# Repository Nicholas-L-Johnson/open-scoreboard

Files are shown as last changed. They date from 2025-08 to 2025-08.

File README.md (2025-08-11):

## Open Scoreboard

This project is a pocket scoreboard with Android/iOS/WatchOS apps.

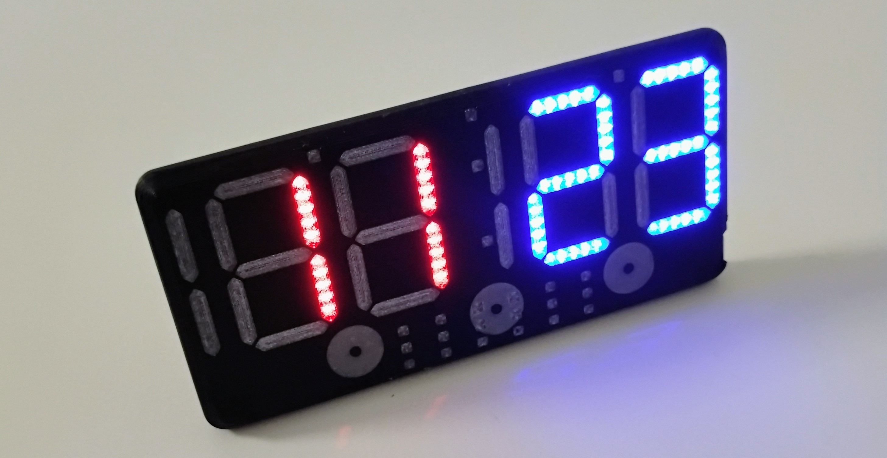
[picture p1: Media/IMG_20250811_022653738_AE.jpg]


The goal is a mass market product.  It beats out the existing devices on the market in features and price.



It really is small enough to fit in a pocket, and the battery lasts for up to 2 days of continuuous display on one charge.

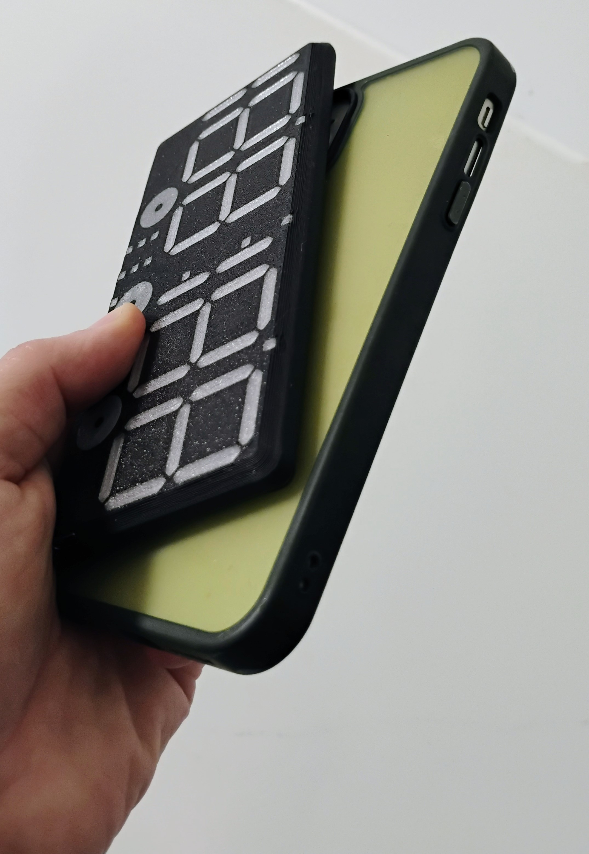
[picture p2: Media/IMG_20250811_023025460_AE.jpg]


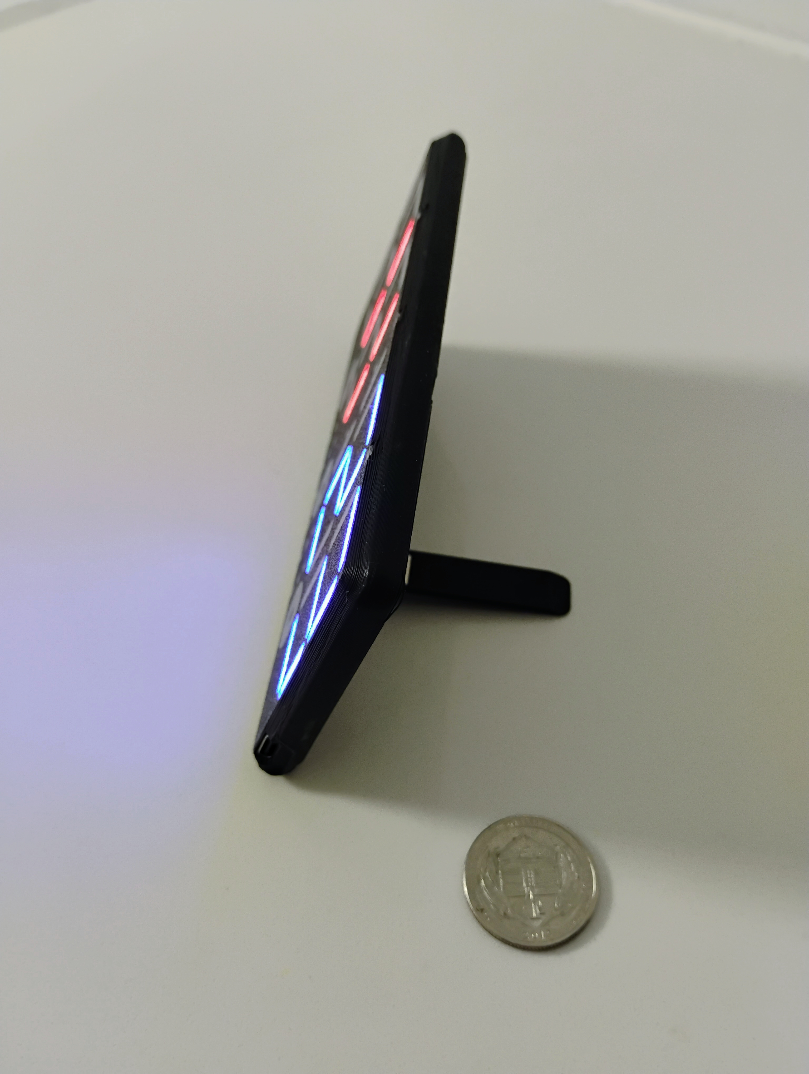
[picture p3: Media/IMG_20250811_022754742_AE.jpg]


It has some other modes too, a countdown timer and alarm clock


This project may be slightly doomed.  It will take about 35K to get the certifications, testing, and llc up to the level where these can be sold.  The real killer is the massive fee to use bluetooth.

I could seek a loan, but I am pretty against that at this point.  The app is not nearly ready, and it definitly needs to be migrated to a 4 layer board if I want to pass FCC testing.

Anyway, I'll keep working and maybe when it's ready there will be some cash I can spare on it.

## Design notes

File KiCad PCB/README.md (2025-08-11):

## PCB files

These are the hardware design files for the open scoreboard project.

The current design is based off of an nRF52833 with an RGB LED grid laid out as a scoreboard.

Version 0.1 controlled the LED's directly.  
This worked but required many pins and led to flickering and ghosting and lacked some creature comforts such as recharchable battery. 4 LEDs per segment also did not look great.

Version 0.2 attepted to switch to WLEDs.
This pulled far too much current and created heat problems. Battery charging and the larger NFC antenna were a success though.

The current version, 0.3 goes back to normal LEDs, but passes the control off to an LED grid controller. With lipo battery, improved NFC, Piezo, USB, 5 LED segments, and lower part count.

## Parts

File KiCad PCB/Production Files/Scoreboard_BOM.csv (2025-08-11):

# | Reference | Value | Datasheet | Footprint | Qty | Manufacturer | Package | Price | Vendor | DNP | Notes | Part Number | LCSC Part Number | Website
1 | BT2 | 18650_Cell_Holder | https://www.lcsc.com/datasheet/lcsc_datasheet_2211291730_MYOUNG-BH-18650-A1AJ005_C5290176.pdf | User_Footprints:18650_Cell_Holder | 1 | MYOUNG | THT | .42 | LCSC | DNP |  | BH-18650-A1AJ005 | C5290176 | https://www.lcsc.com/product-detail/Button-And-Strip-Battery-Connector_MYOUNG-BH-18650-A1AJ005_C5290176.html
2 | BZ2 | Buzzer | https://www.lcsc.com/datasheet/lcsc_datasheet_2410010301_KELIKING-KLJ-7525-3627_C189208.pdf | User_Footprints:XDCR_CMT-7525-80-SMT-TR | 1 | KELIKING | SMD | .4741 | LCSC |  | 2-4.5V 85dB 2.731kHz | KLJ-7525-3627 | C189208 | https://www.lcsc.com/product-detail/Buzzers_KELIKING-KLJ-7525-3627_C189208.html
3 | C1,C2,C9 | 1u | https://datasheet.lcsc.com/lcsc/2209191700_Samsung-Electro-Mechanics-CL10A105KO8NNNC_C1592.pdf | User_Footprints:C_0603_1608Metric | 3 | Samsung Electro-Mechanics | 0603 | .0032 | LCSC |  | 16V 10% | CL10A105KO8NNNC | C1592 | https://www.lcsc.com/product-detail/Multilayer-Ceramic-Capacitors-MLCC-SMD-SMT_Samsung-Electro-Mechanics-CL10A105KO8NNNC_C1592.html
4 | C3,C4 | 18p | https://datasheet.lcsc.com/lcsc/2208181800_FOJAN-FCC0603N180J500CT_C5137620.pdf | User_Footprints:C_0603_1608Metric | 2 | FOJAN | 0603 | .0027 | LCSC |  | 50V 5% | FCC0603N180J500CT | C5137620 | https://www.lcsc.com/product-detail/Multilayer-Ceramic-Capacitors-MLCC-SMD-SMT_FOJAN-FCC0603N180J500CT_C5137620.html
5 | C5,C6 | 4u7 | https://datasheet.lcsc.com/lcsc/2208051100_HRE-CSA0603X5R475K6R3JT_C3015159.pdf | User_Footprints:C_0603_1608Metric | 2 | HRE | 0603 | .0050 | LCSC |  | 6.3V 10% | CGA0603X5R475K6R3JT | C7503506 | https://www.lcsc.com/product-detail/Multilayer-Ceramic-Capacitors-MLCC-SMD-SMT_HRE-CGA0603X5R475K6R3JT_C7503506.html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
6 | C7,C8,C10 | 100n | https://datasheet.lcsc.com/lcsc/2304140030_Samsung-Electro-Mechanics-CL10B104KA8NNNC_C1590.pdf | Capacitor_SMD:C_0603_1608Metric | 3 | Samsung Electro-Mechanics | 0603 | .0028 | LCSC |  | 25V 10% | CL10B104KA8NNNC | C1590 | https://www.lcsc.com/product-detail/Multilayer-Ceramic-Capacitors-MLCC-SMD-SMT_Samsung-Electro-Mechanics-CL10B104KA8NNNC_C1590.html
7 | D1 | LED | https://www.lcsc.com/datasheet/lcsc_datasheet_2402181505_XINGLIGHT-XL-1608SURC-06_C965799.pdf | LED_SMD:LED_0603_1608Metric | 1 | XINGLIGHT | 0603 | .003 | LCSC |  | 20mA | XL-1608SURC-06 | C965799 | https://www.lcsc.com/product-detail/span-style-background-color-ff0-LED-span-Indication-Discrete_XINGLIGHT-XL-1608SURC-06_C965799.html
8 | D2,D3,D4,D5,D6,D7,D8,D9,D10,D11,D12,D13,D14,D15,D16,D17,D18,D19,D20,D21,D22,D23,D24,D25,D26,D27,D28,D29,D30,D31,D32,D33,D34,D35,D36,D37,D38,D39,D40,D41,D42,D43,D44,D45,D46,D47,D48,D49,D50,D51,D52,D53,D54,D55,D56,D57,D58,D59,D60,D61,D62,D63,D64,D65,D66,D67,D68,D69,D70,D71,D72,D73,D74,D75,D76,D77,D78,D79,D80,D81,D82,D83,D84,D85,D86,D87,D88,D89,D90,D91,D92,D93,D94,D95,D96,D97,D98,D99,D100,D101,D102,D103,D104,D105,D106,D107,D108,D109,D110,D111,D112,D113,D114,D115,D116,D117,D118,D119,D120,D121,D122,D123,D124,D125,D126,D127,D128,D129,D130,D131,D132,D133,D134,D135,D136,D137,D138,D139,D140,D141,D142,D143,D144,D145,D146,D147,D148,D149,D150,D151,D152,D153,D154,D155,D156,D157,D158,D159,D160,D161,D162,D163,D164,D165,D166,D167,D168,D169,D170,D171,D172,D173,D174,D175,D176,D177,D178,D179,D180,D181,D182,D183,D184 | LED_RGAB | https://datasheet.lcsc.com/lcsc/2108150330_Foshan-NationStar-Optoelectronics-NH-B2020RGBA-HF_C2874116.pdf | User_Footprints:RGB_LED_NH-B2020RGBA-HF | 183 | Foshan NationStar Optoelectronics | LED RGAB 2020 | .0081 | LCSC |  | SMD | NH-B2020RGBA-HF | C2874116 | https://www.lcsc.com/product-detail/Light-Emitting-Diodes-LED_Foshan-NationStar-Optoelectronics-NH-B2020RGBA-HF_C2874116.html
9 | J2 | USB-C_Port | https://www.lcsc.com/datasheet/lcsc_datasheet_2312191005_G-Switch-GT-USB-7014A_C963371.pdf | User_Footprints:GCT_USB4110GFA | 1 | G-Switch | SMD | .0952 | LCSC |  | 5A | GT-USB-7014A | C963371 | https://www.lcsc.com/product-detail/USB-Connectors_G-Switch-GT-USB-7014A_C963371.html
10 | J3 | TP4057 | https://www.vishay.com/docs/83316/sot236l.pdf | User_Footprints:SOT-23-6 | 1 | YONGYUTAI | SOT-23-6L | .0265 | LCSC |  | 0.3V-6.5V 600mA | TP4057 | C20199358 | https://www.lcsc.com/product-detail/Battery-Management_YONGYUTAI-TP4057_C20199358.html
11 | Q5,Q6,Q7 | HL-2302V | https://datasheet.lcsc.com/lcsc/2306211455_HL-2302V_C7431443.pdf | Package_TO_SOT_SMD:SOT-23 | 3 | HL | SOT-23 | .0089 | LCSC |  | N-Channel 3A Mosfet | 2302V | C7431443 | https://www.lcsc.com/product-detail/MOSFETs_HL-2302V_C7431443.html
12 | R8 | 10K | https://www.lcsc.com/datasheet/lcsc_datasheet_2411071710_FOJAN-FRC0603J103-TS_C2930027.pdf | User_Footprints:R_0603_1608Metric | 1 | FOJAN | 0603 | .0008 | LCSC |  | 100mW 5% | FRC0603J103 TS | C2930027 | https://www.lcsc.com/product-detail/Chip-Resistor-Surface-Mount_FOJAN-FRC0603J103-TS_C2930027.html
13 | R25 | 100 | https://www.lcsc.com/datasheet/lcsc_datasheet_2411071710_FOJAN-FRC0603J101-TS_C2907089.pdf | User_Footprints:R_0603_1608Metric | 1 | FOJAN | 0603 | .0008 | LCSC |  | 100mW 5% | FRC0603J101 TS | C2907089 | https://www.lcsc.com/product-detail/Chip-Resistor-Surface-Mount_FOJAN-FRC0603J101-TS_C2907089.html
14 | R1,R2,R4 | 5K1 | https://datasheet.lcsc.com/lcsc/2304140030_YAGEO-RC0603FR-075K1L_C105580.pdf | User_Footprints:R_0603_1608Metric | 3 | YAGEO | 0603 | .0013 | LCSC |  | 100mW 1% | RC0603FR-075K1L | C105580 | https://www.lcsc.com/product-detail/Chip-Resistor-Surface-Mount_YAGEO-RC0603FR-075K1L_C105580.html
15 | R24,R27,R46,R48,R49,R50,R58,R59,R60,R62 | 21 | https://datasheet.lcsc.com/lcsc/2308241947_FOJAN-FRC0603F21R0TS_C5713281.pdf | User_Footprints:R_0603_1608Metric | 10 | FOJAN | 0603 | .0009 | LCSC |  | 100mW 1% | FRC0603F21R0TS | C5713281 | https://www.lcsc.com/product-detail/Chip-Resistor-Surface-Mount_FOJAN-FRC0603F21R0TS_C5713281.html
16 | R28,R29,R47,R51,R61 | 43 | https://datasheet.lcsc.com/lcsc/2308241947_FOJAN-FRC0603F43R0TS_C2907039.pdf | User_Footprints:R_0603_1608Metric | 5 | FOJAN | 0603 | .0009 | LCSC |  | 100mW 1% | FRC0603F43R0TS | C2907039 | https://www.lcsc.com/product-detail/Chip-Resistor-Surface-Mount_FOJAN-FRC0603F43R0TS_C2907039.html
17 | R3,R20,R22 | 1K | https://datasheet.lcsc.com/lcsc/2308241947_FOJAN-FRC0603J102-TS_C2907113.pdf | User_Footprints:R_0603_1608Metric | 3 | FOJAN | 0603 | .0008 | LCSC |  | 100mW 1% | FRC0603J102 TS | C2907113 | https://www.lcsc.com/product-detail/Chip-Resistor-Surface-Mount_FOJAN-FRC0603J102-TS_C2907113.html
18 | R5,R6 | 2K | https://www.lcsc.com/datasheet/lcsc_datasheet_2411071710_FOJAN-FRC0603J202-TS_C2907137.pdf | User_Footprints:R_0603_1608Metric | 2 | Fojan | 0603 | .0008 | LCSC |  | 100mW 5% | FRC0603J202 TS | C2907137 | https://www.lcsc.com/product-detail/Chip-Resistor-Surface-Mount_FOJAN-FRC0603J202-TS_C2907137.html
19 | R7,R21 | 100K | https://www.lcsc.com/datasheet/lcsc_datasheet_2411071710_FOJAN-FRC0603J104-TS_C2907088.pdf | User_Footprints:R_0603_1608Metric | 2 | FOJAN | 0603 | .0007 | LCSC |  | 100mW 5% | FRC0603J104 TS | C2907088 | https://www.lcsc.com/product-detail/Chip-Resistor-Surface-Mount_FOJAN-FRC0603J104-TS_C2907088.html
20 | SW1,SW2,SW3 | SW_Push | https://www.lcsc.com/datasheet/lcsc_datasheet_2110151630_XKB-Connection-TS-1187A-C-D-B_C318888.pdf | User_Footprints:SW4_1437565_TEC | 3 | XKB Connection | SMD | .0368 | LCSC |  | 50mA | TS-1187A-C-D-B | C318888 | https://www.lcsc.com/product-detail/Tactile-Switches_XKB-Connection-TS-1187A-C-D-B_C318888.html
21 | U1 | BC833M | https://static1.squarespace.com/static/561459a2e4b0b39f5cefa12e/t/63de7682a33fae7d727f1dff/1675523715100/BC833M-p+Product_Specifications.pdf | User_Footprints:XCVR_BC833M | 1 | Fanstel Corp. | SMD | 5.00 | LCSC |  | nRF52833 | BC833M |  | https://www.fanstel.com/bc833
22 | U2 | DW01A | https://www.lcsc.com/datasheet/lcsc_datasheet_2411121620_Slkor-SLKORMICRO-Elec--DW01A_C42380662.pdf | Package_TO_SOT_SMD:SOT-23-6 | 1 | Slkor | SOT-23-6 | .0164 | LCSC |  | SMD | DW01A | C318888 | https://www.lcsc.com/product-detail/Battery-Management_Slkor-SLKORMICRO-Elec-DW01A_C42380662.html?s_z=n_DW01A
23 | U3 | IS31FL3729 | https://www.lcsc.com/datasheet/lcsc_datasheet_2410121548_ISSI-Integrated-Silicon-Solution-IS31FL3729-QFLS4-TR_C2940549.pdf | Package_DFN_QFN:QFN-32-1EP_4x4mm_P0.4mm_EP2.9x2.9mm_ThermalVias | 1 | Integrated Silicon Solution (ISSI) | QFN-32-EP(4x4) | .94 | LCSC |  | SMD | IS31FL3729-QFLS4-TR | C2940549 | https://www.lcsc.com/product-detail/LED-Drivers_ISSI-Integrated-Silicon-Solution-IS31FL3729-QFLS4-TR_C2940549.html

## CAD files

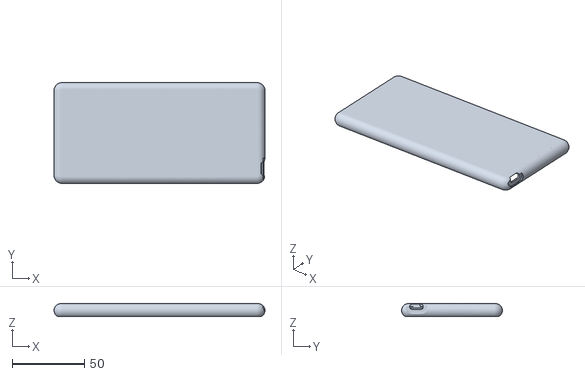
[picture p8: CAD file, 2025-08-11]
Housing/Part13^Cover.STL
145.6 x 69.6 x 8.87

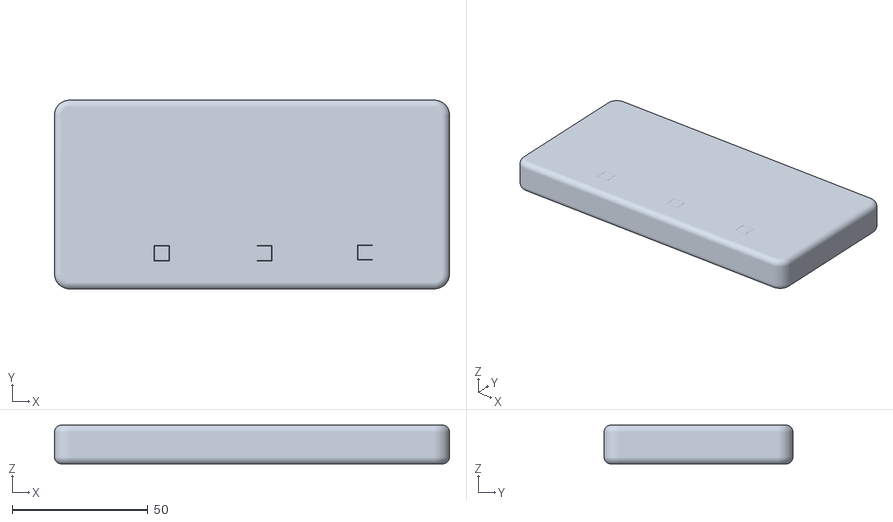
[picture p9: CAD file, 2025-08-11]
Housing/Cover - Part13^Cover-1.STL
145.6 x 69.6 x 14.3

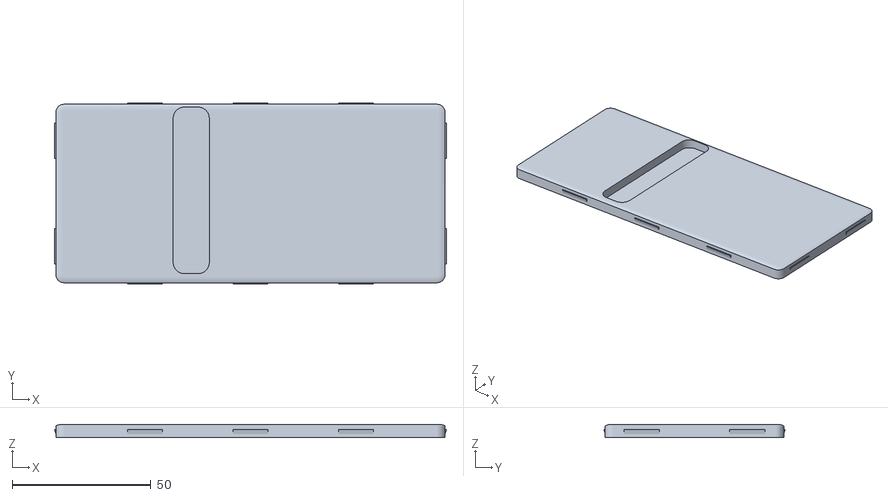
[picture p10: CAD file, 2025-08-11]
Housing/Part14^Cover.STL
141.5 x 65.5 x 4.80

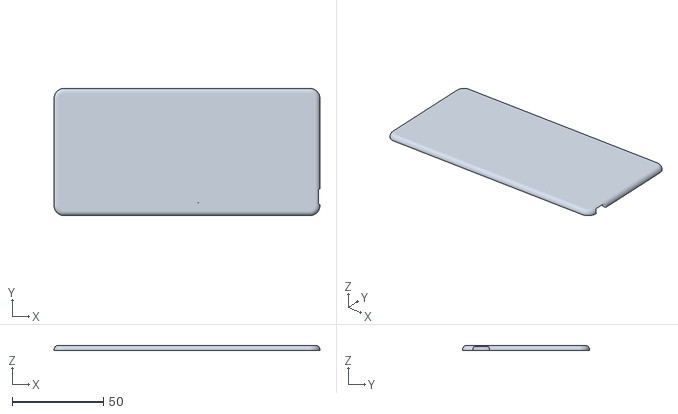
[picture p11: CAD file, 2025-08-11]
Housing/Part13^Cover_Chopped.STL
145.6 x 69.6 x 3.00

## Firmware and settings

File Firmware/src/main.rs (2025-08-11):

#![no_std]
#![no_main]

use core::cell::RefCell;

use cortex_m_rt::{entry, exception};
#[cfg(feature = "defmt")]
use defmt_rtt as _;
use embassy_boot_nrf::*;
use embassy_nrf::nvmc::Nvmc;
use embassy_nrf::wdt::{self, HaltConfig, SleepConfig};
use embassy_sync::blocking_mutex::Mutex;

#[entry]
fn main() -> ! {
    let p = embassy_nrf::init(Default::default());
    #[cfg(feature = "defmt")]
    info!("bootloader");

    // Uncomment this if you are debugging the bootloader with debugger/RTT attached,
    // as it prevents a hard fault when accessing flash 'too early' after boot.
    
        for i in 0..10000000 {
            cortex_m::asm::nop();
        }


    let mut wdt_config = wdt::Config::default();
    wdt_config.timeout_ticks = 32768 * 5; // timeout seconds
    wdt_config.action_during_sleep = SleepConfig::RUN;
    wdt_config.action_during_debug_halt = HaltConfig::PAUSE;

    let flash = WatchdogFlash::start(Nvmc::new(p.NVMC), p.WDT, wdt_config);
    let flash = Mutex::new(RefCell::new(flash));

    let config = BootLoaderConfig::from_linkerfile_blocking(&flash, &flash, &flash);
    let active_offset = config.active.offset();
    let bl: BootLoader = BootLoader::prepare(config);

    unsafe { bl.load(active_offset) }
}

#[no_mangle]
#[cfg_attr(target_os = "none", link_section = ".HardFault.user")]
unsafe extern "C" fn HardFault() {
    cortex_m::peripheral::SCB::sys_reset();
}

#[exception]
unsafe fn DefaultHandler(_: i16) -> ! {
    const SCB_ICSR: *const u32 = 0xE000_ED04 as *const u32;
    let irqn = core::ptr::read_volatile(SCB_ICSR) as u8 as i16 - 16;

    panic!("DefaultHandler #{:?}", irqn);
}

#[panic_handler]
fn panic(_info: &core::panic::PanicInfo) -> ! {
    cortex_m::asm::udf();
}
